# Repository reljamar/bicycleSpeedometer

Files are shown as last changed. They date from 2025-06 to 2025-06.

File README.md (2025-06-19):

# BICYCLE SPEEDOMETER PROJECT
*A simple LCD bicycle speedometer. This project is a work in progress.*

## Purpose
This project is an exercise in embedded systems, and as an excuse to use 7-segment LCDs. With some refinement, it can be turned into a useable product. This is a home project, not optimized for mass production, but rather for hand-soldering, simple handling, and parts availability. The housing can be 3D printed.

## Description
A custom low-power digital speedometer for a bicycle, built around an STM32 microcontroller with integrated LCD driver. This project emphasizes hardware efficiency, clear UI, and compact design — using a reed switch instead of a hall sensor for speed sensing, and a low-power LCD segment display. It is still under development, with core functionality working and additional features planned.

## Overview
- Displays real-time speed on a 3-digit 7-segment LCD with one decimal precision
- Reed switch and magnet used for wheel rotation sensing
- Custom PCB with STM32L053R6T6, featuring onboard LCD driving and USB debug interface
- 350 mAh Li-Po battery with integrated charging via USB
- Buttons for scrolling through displays (current speed, average speed since reset, distance since reset, driving time since reset, odometer)
- Designed for ultra-low power operation (with further optimization planned)

## Project status
Currently the project can achieve the core function of the speedometer: measure the speed, and display it on the display, as well as charge the battery.
<p align="center">
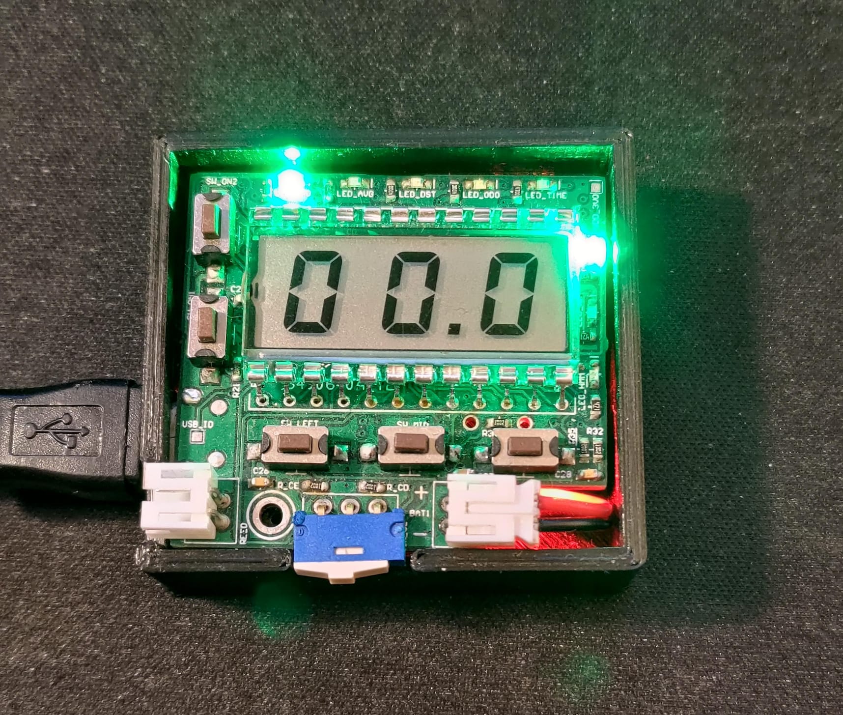
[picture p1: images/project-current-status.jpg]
Current build

</p>
The magnet and sensor are on the bicycle which couldn't fit in this picture. Top cover is also not shown.

## System architecture
### Microcontroller
The system is based on a STM32L053R6T6 microcontroller. The MCU has an LCD driver built-in, and is low-power. The CPU is a Cortex-M0, which is plenty for this application. The MCU reads the reed switch status, calculates the speed, displays it on the LCD, monitors the battery, stores data.
### Display
The display on this device is made of two parts: the 7-segment LCD, and indication diodes. The diodes show the meaning of the current information on the display, and the units. While the LCD power consumption is very low, the diodes are not an optimal choice for low power. It is possible to order custom LCDs for a reasonable price, so a future addition to the project will be to replace the indication diodes to marked LCD segments. Each LCD segment has a separate driving pin on the microcontroller. The pins are chosen in such a way to simplify routing. A look-up table is created in software to turn on the correct segments for displaying each digit.
### Sensor
The sensor is activated by a magnet attached to the wheel spokes. The sensor is a simple reed switch. This is done to minimize current draw. A Hall effect sensor or Hall effect switch constantly consumes a few mA, whereas the reed switch only draws current during the small percantage of the rotation period when it is closed by the magnet on the wheel, and that current is limited by a pull-up resistor. Due to the nature of using a mechanical switch, it is prone to bouncing. That is why an RC filter is implemented, as well as debounce software. The magnet is strong enough to keep the switch closed for a significant enough portion of the period to allow time for the bouncing to settle.
<p align="center">
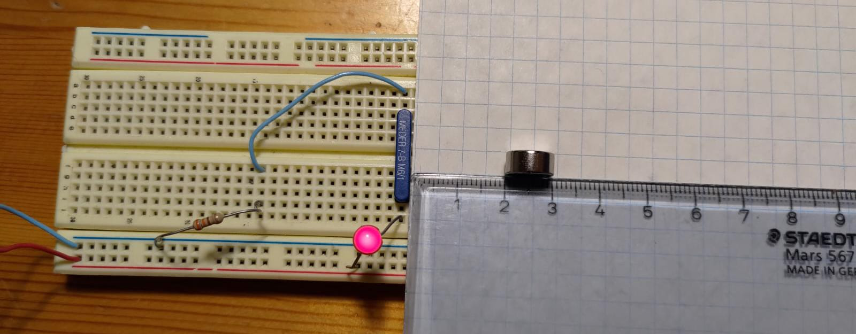
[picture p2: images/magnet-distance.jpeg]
Magnet activation distance

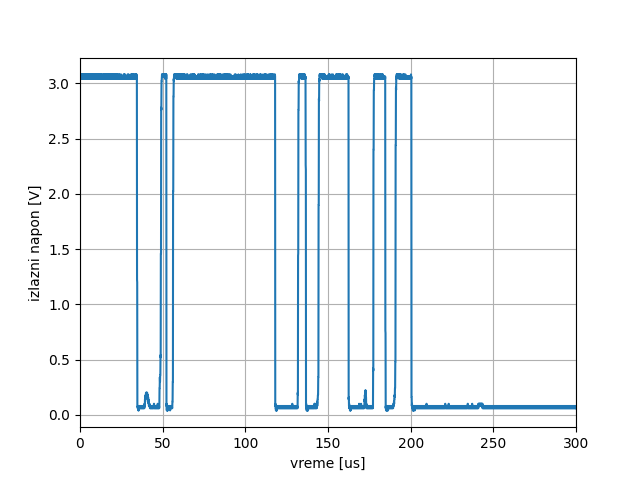
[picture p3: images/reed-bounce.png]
Reed bouncing signal

</p>
The image on the left shows the activation distance for the magnet. The image on the right is the reed switch's bouncing effect.

### Battery
The project uses a massive 350mAh rechargable Li-Po battery. The battery is charged via USB through a power management IC, which handles constant current and constant voltage handling, as well as power supply switchover. With more detailed analysis of power optimization, this battery can be replaced with a non-rechargable coin cell.
### Speed calculation
The speed is calculated based on the rotation period of the wheel: with a known diameter (the user must input the diameter of the exact wheel on the bicycle) and a measured time for a full rotation, it is easy to calculate the current speed. However, in order to not update the display with every wheel rotation (it would be difficult for the rider to read the display with such rapid changes), the measurements are averaged over a 2-second period. At the end of each 2-second period, the speed during that period is calculated, and the display is refreshed. If one or zero magnet passes are detected during this 2-second window, the displayed speed is 0. Therefore, there is a minimum measurable speed, which is just under 1m/s for a 27.5-inch wheel. This speed is slower than walking speed, and riders are not expected to be cycling at such low speeds.
### Layout
There are no high-speed signals here. The layout is placed on a 4-layer board solely due to space constraints. The MCU and some components are placed on the same layer but below the LCD (see 3D render without the LCD shown).
<p align="center">
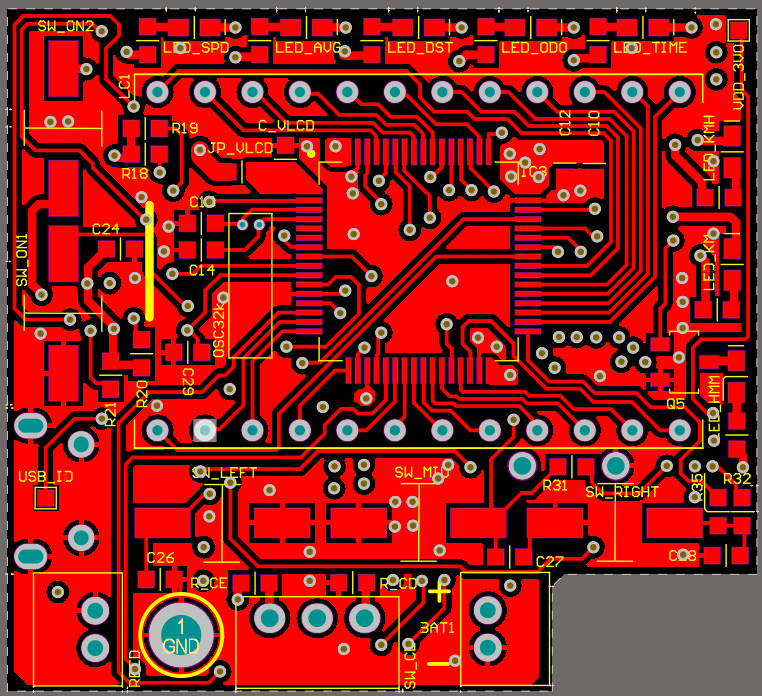
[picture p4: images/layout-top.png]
Top layer

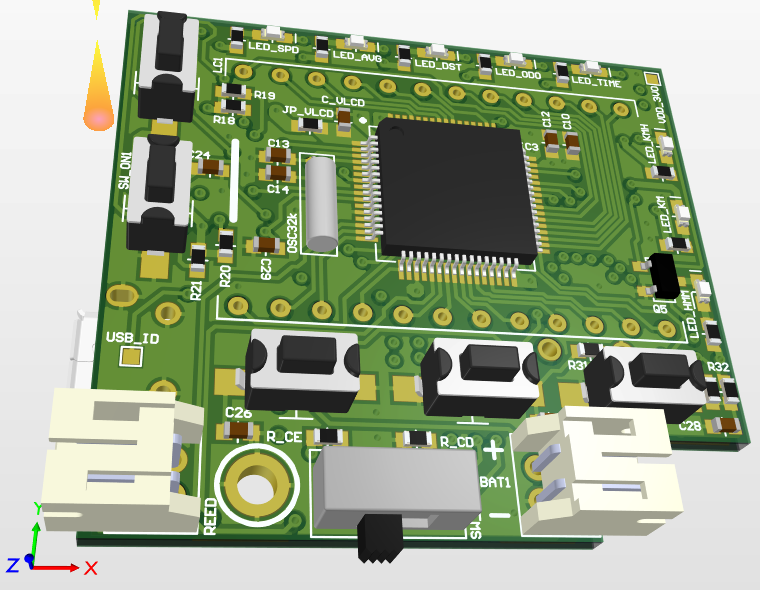
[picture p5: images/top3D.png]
3D render

</p>

## Firmware
### Implemented features
- [x] Lookup table for LCD digit segments
- [x] Speed calculation
- [x] Reed relay debouncing (HW + SW)
- [x] Power on/off control
- [x] Status LED control
- [x] Battery charging
### Planned features
- [ ] Low power and stanby modes
- [ ] Average speed calculation, distance calculation, ride time calculation, odometer
- [ ] Non-volatile trip data storage
- [ ] Previous/Next/Select screen navigation handling
- [ ] Wheel size selection menu

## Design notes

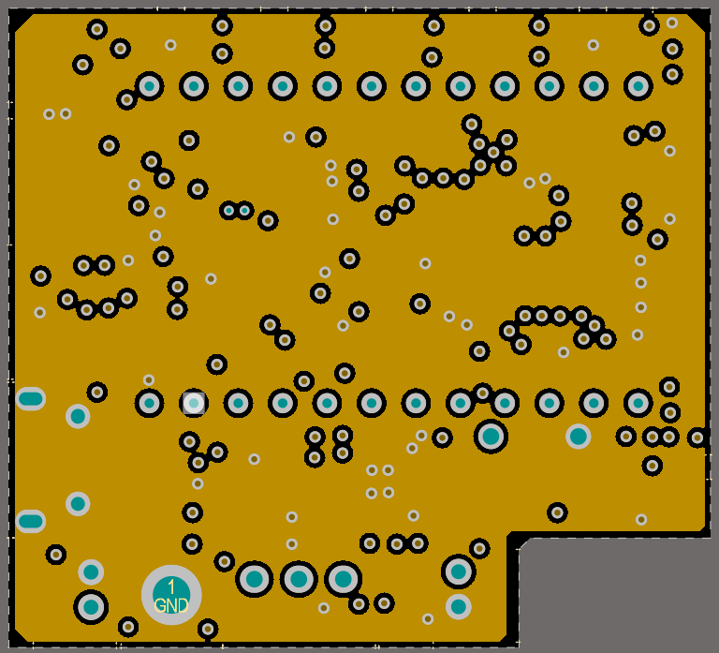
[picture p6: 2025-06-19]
hardware/layout/mid1.png

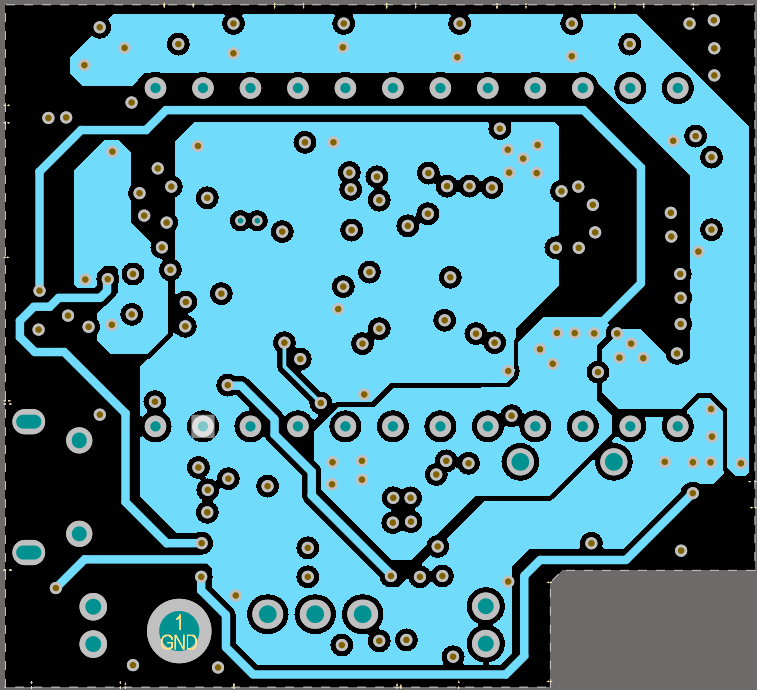
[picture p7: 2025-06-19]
hardware/layout/mid2.png

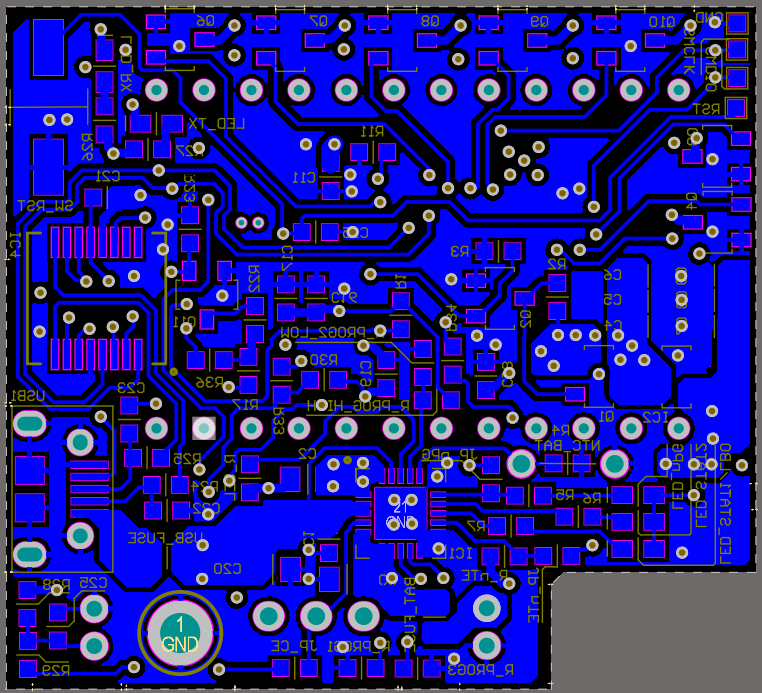
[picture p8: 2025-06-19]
hardware/layout/bot.png

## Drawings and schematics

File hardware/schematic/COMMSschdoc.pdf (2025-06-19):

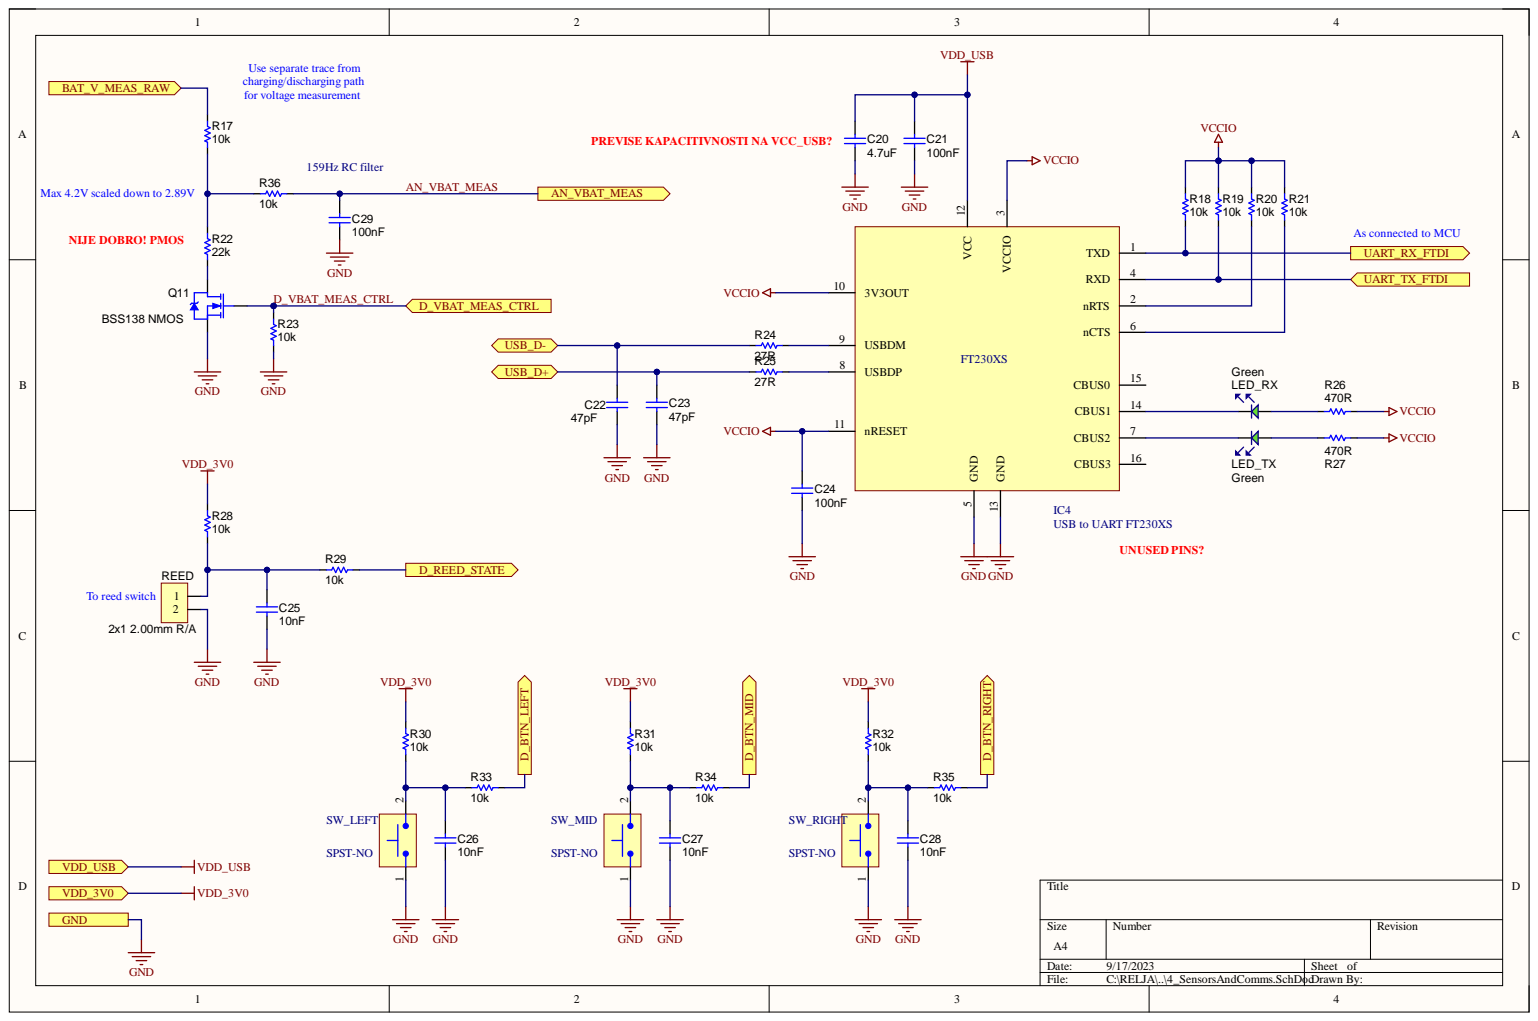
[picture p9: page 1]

Use separate trace from
charging/discharging path
for voltage measurement

As connected to MCU
UART_RX_FTDI

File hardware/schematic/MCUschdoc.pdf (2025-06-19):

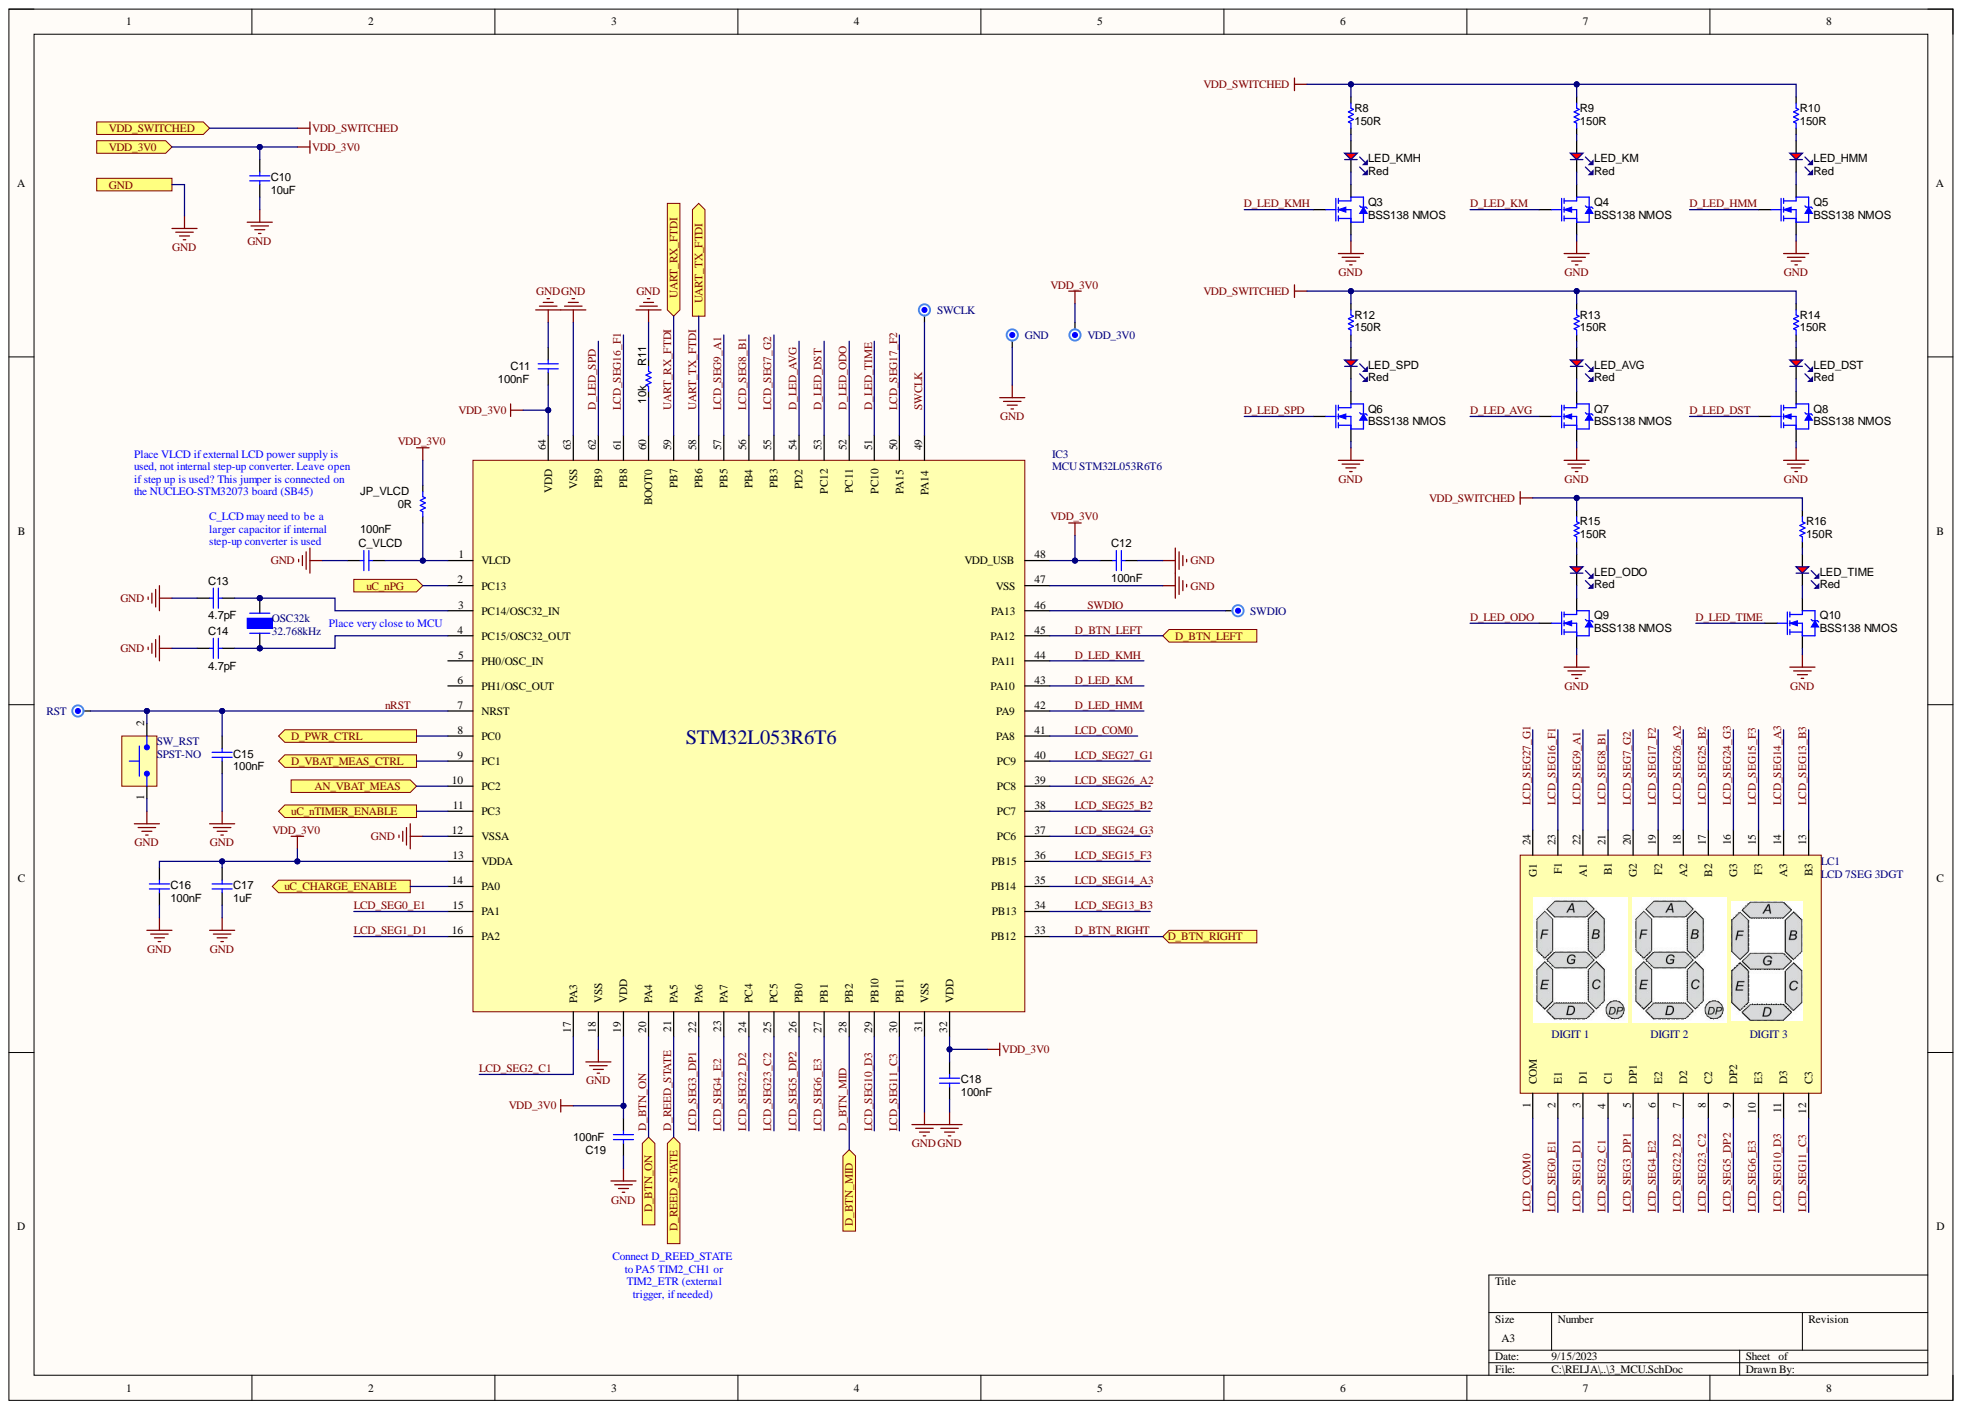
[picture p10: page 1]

Place VLCD if external LCD power supply is
used, not internal step-up converter. Leave open
if step up is used? This jumper is connected on
the NUCLEO-STM32073 board (SB45)

C_LCD may need to be a
larger capacitor if internal
step-up converter is used

Place very close to MCU

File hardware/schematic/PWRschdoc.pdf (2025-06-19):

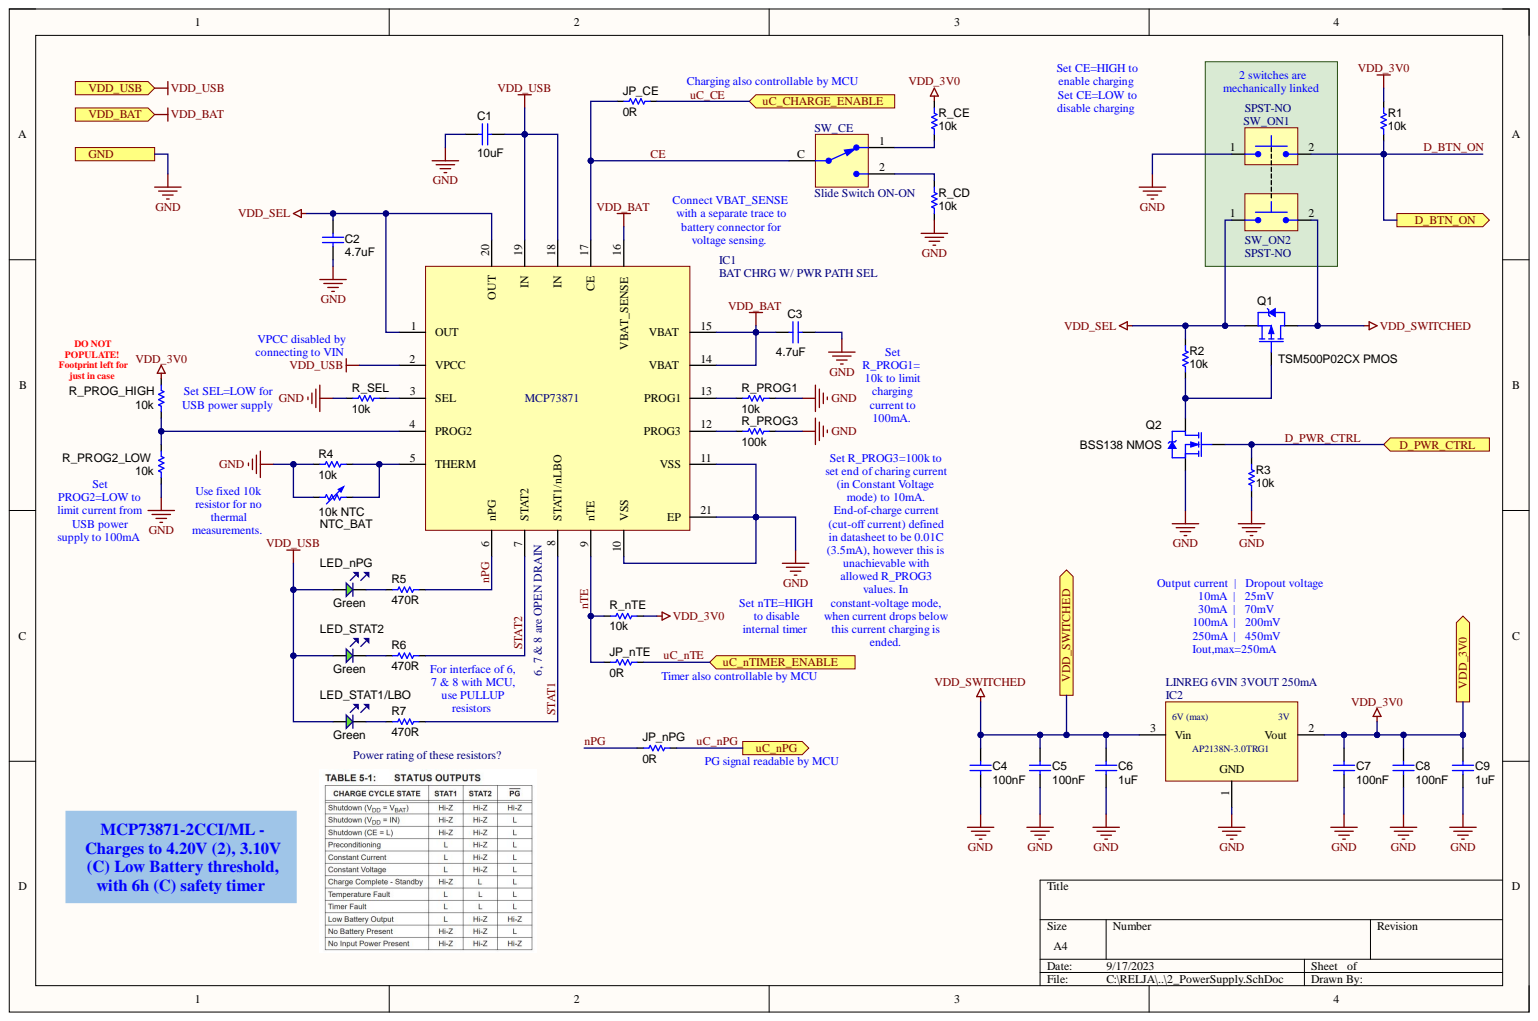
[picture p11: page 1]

Set CE=HIGH to
enable charging
Set CE=LOW to
disable charging

Charging also controllable by MCU

Slide Switch ON-ON

with a separate trace to
battery connector for
voltage sensing.
BAT CHRG W/ PWR PATH SEL

Set SEL=LOW for
USB power supply

Set R_PROG3=100k to
set end of charing current
(in Constant Voltage
mode) to 10mA.
End-of-charge current
(cut-off current) defined
in datasheet to be 0.01C
(3.5mA), however this is
unachievable with
allowed R_PROG3
values. In
constant-voltage mode,
when current drops below

Output current | Dropout voltage

this current charging is

uC_nTE
Timer also controllable by MCU

Green
Power rating of these resistors?

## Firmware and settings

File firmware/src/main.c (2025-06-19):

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
/* Includes ------------------------------------------------------------------*/
#include "main.h"

/* USER CODE BEGIN PD */
#define UART_MESSAGE_CHARACTER_COUNT (5)

//DIGITS ARE COUNTED LEFT TO RIGHT, STARTING FROM 1
//DEFINE ACTIVE SEGMENTS FOR EACH DIGIT
#define LCD_DIGIT1_0	(0x00010307)
#define LCD_DIGIT1_1	(0x00000104)
#define LCD_DIGIT1_2	(0x08000303)
#define LCD_DIGIT1_3	(0x08000306)
#define LCD_DIGIT1_4	(0x08010104)
#define LCD_DIGIT1_5	(0x08010206)
#define LCD_DIGIT1_6	(0x08010207)
#define LCD_DIGIT1_7	(0x00000304)
#define LCD_DIGIT1_8	(0x08010307)
#define LCD_DIGIT1_9	(0x08010306)

//#define LCD_DP_1		(0x00000008)

#define LCD_DIGIT2_0	(0x06C20010)
#define LCD_DIGIT2_1	(0x02800000)
#define LCD_DIGIT2_2	(0x06400090)
#define LCD_DIGIT2_3	(0x06C00080)
#define LCD_DIGIT2_4	(0x02820080)
#define LCD_DIGIT2_5	(0x04C20080)
#define LCD_DIGIT2_6	(0x04C20090)
#define LCD_DIGIT2_7	(0x06800000)
#define LCD_DIGIT2_8	(0x06C20090)
#define LCD_DIGIT2_9	(0x06C20080)

#define LCD_DP_2		(0x00000020)

#define LCD_DIGIT3_0	(0x0000EC40)
#define LCD_DIGIT3_1	(0x00002800)
#define LCD_DIGIT3_2	(0x01006440)
#define LCD_DIGIT3_3	(0x01006C00)
#define LCD_DIGIT3_4	(0x0100A800)
#define LCD_DIGIT3_5	(0x0100CC00)
#define LCD_DIGIT3_6	(0x0100CC40)
#define LCD_DIGIT3_7	(0x00006800)
#define LCD_DIGIT3_8	(0x0100EC40)
#define LCD_DIGIT3_9	(0x0100EC00)

#define HTIM22_FREQUENCY	(32768)

#define WHEEL_CIRCUMFERENCE	(2.105)
/* USER CODE END PD */

LCD_HandleTypeDef hlcd;

TIM_HandleTypeDef htim2;
TIM_HandleTypeDef htim21;
TIM_HandleTypeDef htim22;

/* USER CODE BEGIN PV */
volatile uint8_t magnetCounter = 0;	//count magnet passes
volatile uint32_t rotationTimerCounts = 0;	//measure time it takes for (magnetCounter) times of the wheel rotation, in timer counts
volatile uint8_t timer2sFlag = 0;	//flag to indicate 2s timer has run out
volatile uint8_t TIM22startedFlag = 0;
/* USER CODE END PV */

void SystemClock_Config(void);
static void MX_GPIO_Init(void);
static void MX_TIM21_Init(void);
static void MX_LCD_Init(void);
static void MX_TIM2_Init(void);
static void MX_TIM22_Init(void);
/**
  * @brief  The application entry point.
  * @retval int
  */
int main(void)
{
  /* MCU Configuration--------------------------------------------------------*/

  /* Reset of all peripherals, Initializes the Flash interface and the Systick. */
  HAL_Init();

  /* Configure the system clock */
  SystemClock_Config();

  /* Initialize all configured peripherals */
  MX_GPIO_Init();
  MX_TIM21_Init();
  MX_LCD_Init();
  MX_TIM2_Init();
  MX_TIM22_Init();
  /* USER CODE BEGIN 2 */

  HAL_TIM_Base_Start_IT(&htim2); //start timer

  HAL_GPIO_WritePin(GPIOC, GPIO_PIN_0, GPIO_PIN_SET);		//keep device ON

  uint32_t lookupDigit1[10];								//initialize array that will server as a lookup table for DIGIT1
  uint32_t lookupDigit2[10];								//initialize array that will server as a lookup table for DIGIT2
  uint32_t lookupDigit3[10];								//initialize array that will server as a lookup table for DIGIT3

  uint8_t speedDigits[UART_MESSAGE_CHARACTER_COUNT];	//initialize array containing the UART message
  uint8_t localMagnetCounter = 0;						//initialize local magnet pass counter

  float speed;

  speedDigits[0] = '0';
  speedDigits[1] = '0';
  speedDigits[2] = '.';
  speedDigits[3] = '0';
  speedDigits[4] = '\n';

  lookupDigit1[0] = LCD_DIGIT1_0;
  lookupDigit1[1] = LCD_DIGIT1_1;
  lookupDigit1[2] = LCD_DIGIT1_2;
  lookupDigit1[3] = LCD_DIGIT1_3;
  lookupDigit1[4] = LCD_DIGIT1_4;
  lookupDigit1[5] = LCD_DIGIT1_5;
  lookupDigit1[6] = LCD_DIGIT1_6;
  lookupDigit1[7] = LCD_DIGIT1_7;
  lookupDigit1[8] = LCD_DIGIT1_8;
  lookupDigit1[9] = LCD_DIGIT1_9;

  lookupDigit2[0] = LCD_DIGIT2_0;
  lookupDigit2[1] = LCD_DIGIT2_1;
  lookupDigit2[2] = LCD_DIGIT2_2;
  lookupDigit2[3] = LCD_DIGIT2_3;
  lookupDigit2[4] = LCD_DIGIT2_4;
  lookupDigit2[5] = LCD_DIGIT2_5;
  lookupDigit2[6] = LCD_DIGIT2_6;
  lookupDigit2[7] = LCD_DIGIT2_7;
  lookupDigit2[8] = LCD_DIGIT2_8;
  lookupDigit2[9] = LCD_DIGIT2_9;

  lookupDigit3[0] = LCD_DIGIT3_0;
  lookupDigit3[1] = LCD_DIGIT3_1;
  lookupDigit3[2] = LCD_DIGIT3_2;
  lookupDigit3[3] = LCD_DIGIT3_3;
  lookupDigit3[4] = LCD_DIGIT3_4;
  lookupDigit3[5] = LCD_DIGIT3_5;
  lookupDigit3[6] = LCD_DIGIT3_6;
  lookupDigit3[7] = LCD_DIGIT3_7;
  lookupDigit3[8] = LCD_DIGIT3_8;
  lookupDigit3[9] = LCD_DIGIT3_9;

  uint8_t digit1 = 0;
  uint8_t digit2 = 0;
  uint8_t digit3 = 0;

  float rotationTime = 0;	//The time it took to complete (magnetCounter) wheel rotation cycles
  HAL_GPIO_WritePin(GPIOB, GPIO_PIN_9, GPIO_PIN_SET);
  HAL_GPIO_WritePin(GPIOA, GPIO_PIN_11, GPIO_PIN_SET);
  /* USER CODE END 2 */

  /* Infinite loop */
  /* USER CODE BEGIN WHILE */
  while (1)
  {
    /* USER CODE END WHILE */
	  __disable_irq();	//disable interrupts while reading the two second timer flag
	  if(timer2sFlag){
		  localMagnetCounter = magnetCounter;					//copy magnet pass counter to local variable
		  magnetCounter = 0;									//reset magnet counter
		  timer2sFlag = 0;										//clear flag
		  rotationTime = (float)rotationTimerCounts/(32764);	//calculate total time it took to complete (magnetCounter) rotations
		  rotationTimerCounts=0;								//reset the rotation timer counter
		  __enable_irq();										//enable interrupts only after finishing access to the shared variables

		  //speed = localMagnetCounter*1.0525;	//calculate speed based on the number of magnet passes within the two second interval.
												//1.0525 comes from: D*pi/2s, where D is the wheel diameter, 0.67m

		  if(rotationTime == 0){
			  speed = 0;
			  //speed = (localMagnetCounter*WHEEL_CIRCUMFERENCE)/2;
		  }
		  else{
			  speed = (localMagnetCounter*WHEEL_CIRCUMFERENCE)/rotationTime;	//SPEED IS IN m/s!!!
		  }

		  //convert speed to KM/H
		  speed = speed*3.6;

		  // Extract the last two digits before the decimal
		  digit1= ((int)speed / 10) % 10;	//convert calculated digits to their ascii code by adding ascii code for '0'
		  speedDigits[0] = digit1 + '0';

		  digit2 = (int)speed % 10;
		  speedDigits[1] = digit2 + '0';

		  // Extract the first digit after the decimal point
		  digit3 = ((int)(speed * 10) % 10);
		  speedDigits[3] = digit3 + '0';

		  //HAL_UART_Transmit(&huart2, speedDigits, UART_MESSAGE_CHARACTER_COUNT, 100);

		  //write digits on LCD
		  HAL_LCD_Write(&hlcd, LCD_RAM_REGISTER0, ~0xFFFFFFFF, 0);	//clear RAM
		  HAL_LCD_Write(&hlcd, LCD_RAM_REGISTER0, ~0xFFFFFFFF, (lookupDigit1[digit1] | lookupDigit2[digit2] | lookupDigit3[digit3] | LCD_DP_2));
		  HAL_LCD_UpdateDisplayRequest(&hlcd);
	  }
	  else{
		  __enable_irq();	//enable interrupts immediately after reading flag if flag was not set
	  }

	  HAL_Delay(5);
    /* USER CODE BEGIN 3 */
  }
  /* USER CODE END 3 */
}

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
/* USER CODE BEGIN 4 */
void HAL_GPIO_EXTI_Callback(uint16_t GPIO_Pin){

	if (GPIO_Pin == GPIO_PIN_5){	//check if interrupt came from pin 5 (no need to check the port as PA5 is currently the only 0th pin in any port used for interrupts)

		__HAL_TIM_SET_COUNTER(&htim21, 0);	// Reset the timer to count from 0 each time there is an interrupt on PA0
		HAL_TIM_Base_Start_IT(&htim21);  // Start the timer WITH interrupt capability (does nothing if timer is already started)
	}
	if (GPIO_Pin == GPIO_PIN_4){
		HAL_GPIO_WritePin(GPIOC, GPIO_PIN_0, GPIO_PIN_RESET);		//latch device OFF
	}

}
void HAL_TIM_PeriodElapsedCallback(TIM_HandleTypeDef *htim){
	if(htim->Instance == TIM2){ //if timer 2 created the interrupt
		timer2sFlag = 1;
		//HAL_GPIO_TogglePin(GPIOA, GPIO_PIN_2);
	}
	if(htim->Instance == TIM21){
		if (HAL_GPIO_ReadPin(GPIOA, GPIO_PIN_5) == GPIO_PIN_SET) {	//check state of PA0 (REED is connected to this pin)
			// The pin is in a high logic state - REED SWITCH OPEN
			HAL_TIM_Base_Stop(&htim21);	//stop the debounce timer

			//do nothing else
		}
		else {
			// The pin is in a low logic state - REED SWITCH CLOSED
			HAL_TIM_Base_Stop(&htim21);	//stop the debounce timer

			//measure time between two consecutive magnet passes:
			if(TIM22startedFlag){	//timer TIM22 already started
				rotationTimerCounts = rotationTimerCounts + __HAL_TIM_GetCounter(&htim22);
				magnetCounter++;

				HAL_TIM_Base_Stop(&htim22);
				__HAL_TIM_SET_COUNTER(&htim22, 0);	// Reset the timer
				HAL_TIM_Base_Start_IT(&htim22);  	// Start the timer WITH interrupt capability

			}
			else{
				__HAL_TIM_SET_COUNTER(&htim22, 0);	// Reset the timer
				HAL_TIM_Base_Start_IT(&htim22);  // Start the timer WITH interrupt capability

				TIM22startedFlag = 1;

			}
		}
	}
  if(htim->Instance == TIM22){
	  //if TIM22 has run out (after 2s), stop and reset it. Do not restart.
	  HAL_TIM_Base_Stop(&htim22);
	  __HAL_TIM_SET_COUNTER(&htim22, 0);	// Reset the timer

	  TIM22startedFlag = 0;
  }

}

/* USER CODE END 4 */
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


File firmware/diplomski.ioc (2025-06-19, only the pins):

Mcu.UserName=STM32L053R6Tx
PA1.Signal=LCD_SEG0
PA10.Signal=GPIO_Output
PA11.Signal=GPIO_Output
PA13.Signal=SYS_SWDIO
PA14.Signal=SYS_SWCLK
PA15.Signal=LCD_SEG17
PA2.Signal=LCD_SEG1
PA3.Signal=LCD_SEG2
PA4.Signal=GPXTI4
PA5.Signal=GPXTI5
PA6.Signal=LCD_SEG3
PA7.Signal=LCD_SEG4
PA8.Signal=LCD_COM0
PA9.Signal=GPIO_Output
PB0.Signal=LCD_SEG5
PB1.Signal=LCD_SEG6
PB10.Signal=LCD_SEG10
PB11.Signal=LCD_SEG11
PB13.Signal=LCD_SEG13
PB14.Signal=LCD_SEG14
PB15.Signal=LCD_SEG15
PB3.Signal=LCD_SEG7
PB4.Signal=LCD_SEG8
PB5.Signal=LCD_SEG9
PB8.Signal=LCD_SEG16
PB9.Signal=GPIO_Output
PC0.Signal=GPIO_Output
PC10.Signal=GPIO_Output
PC11.Signal=GPIO_Output
PC12.Signal=GPIO_Output
PC14-OSC32_IN.Signal=RCC_OSC32_IN
PC15-OSC32_OUT.Signal=RCC_OSC32_OUT
PC4.Signal=LCD_SEG22
PC5.Signal=LCD_SEG23
PC6.Signal=LCD_SEG24
PC7.Signal=LCD_SEG25
PC8.Signal=LCD_SEG26
PC9.Signal=LCD_SEG27
PD2.Signal=GPIO_Output

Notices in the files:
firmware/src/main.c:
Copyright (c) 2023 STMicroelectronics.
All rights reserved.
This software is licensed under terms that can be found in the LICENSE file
